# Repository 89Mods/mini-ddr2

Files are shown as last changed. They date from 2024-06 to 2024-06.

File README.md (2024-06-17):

# mini-ddr2

DDR2 Memory Controller fit into a 1€ MAX II CPLD with just 240 LUs. Its incredibly slow, but works!

Currently only works with x4 DRAMs. To demonstrate basic functionality, the CPLD is programmed to respond to byte-wide reads/writes on a "flat" address/data bus. ``A_f`` are the 24 address lines, ``Q_f`` is the data bus. Operation is controlled via ``WEb_f`` and ``CS_f`` (not to be confused with the similarly-named DDR2 signals). A ``ready`` output indicates if the last read/write request has completed processing.

# Implementation Details

After releasing the reset input, the CPLD runs through the DDR2 initialization sequence. Slowly. I optimized it for size, not speed, so it takes several tens of thousands of clock cycles to complete. Once it does, the controller enters the main state machine.

When idle, the controller spams DDR2 refresh commands as fast as it can, only interrupted by a falling edge on ``CS_f`` requesting a memory access. ``A_f`` is split into a bank, column and row address and the proper bank and column activated before the memory access.

Both reads and writes use the minimum burst length of 4, but are only byte-wide, using the first two nibbles in the burst, least-significant half first.

At the start of any read or write leaving the idle loop, the controller starts a timer, only precharging the current bank and returning to idle mode once this expires. This allows for further reads or writes to the same bank and row to be registered and processed immediatly.

If the bank or row change, a precharge and then activate are executed to switch to the new addresses. This does not reset the timer.

# Timing

Max tested clock speed for the CPLD is 85MHz. This is divided by two to arrive at the DDR2 clock of 42.5MHz. Works fine, despite violating the min clock speed for the DDR2 chip in the example by over 150MHz.

Quartus says the design does not meet timings above this clock speed. Propagation delay times begin to mess with the timing at this stage anyways.

The best-case scenario is a sequential write, taking 12 CPLD clock cycles (141ns).

The worst case is a non-sequential read requiring a switch to a different row, at 22 CPLD clock cycles (258ns).

It may be possible to improve this by playing with the timing parameters. Sadly, this design uses 240/240 LUs, so there is otherwise no more room for improvement.

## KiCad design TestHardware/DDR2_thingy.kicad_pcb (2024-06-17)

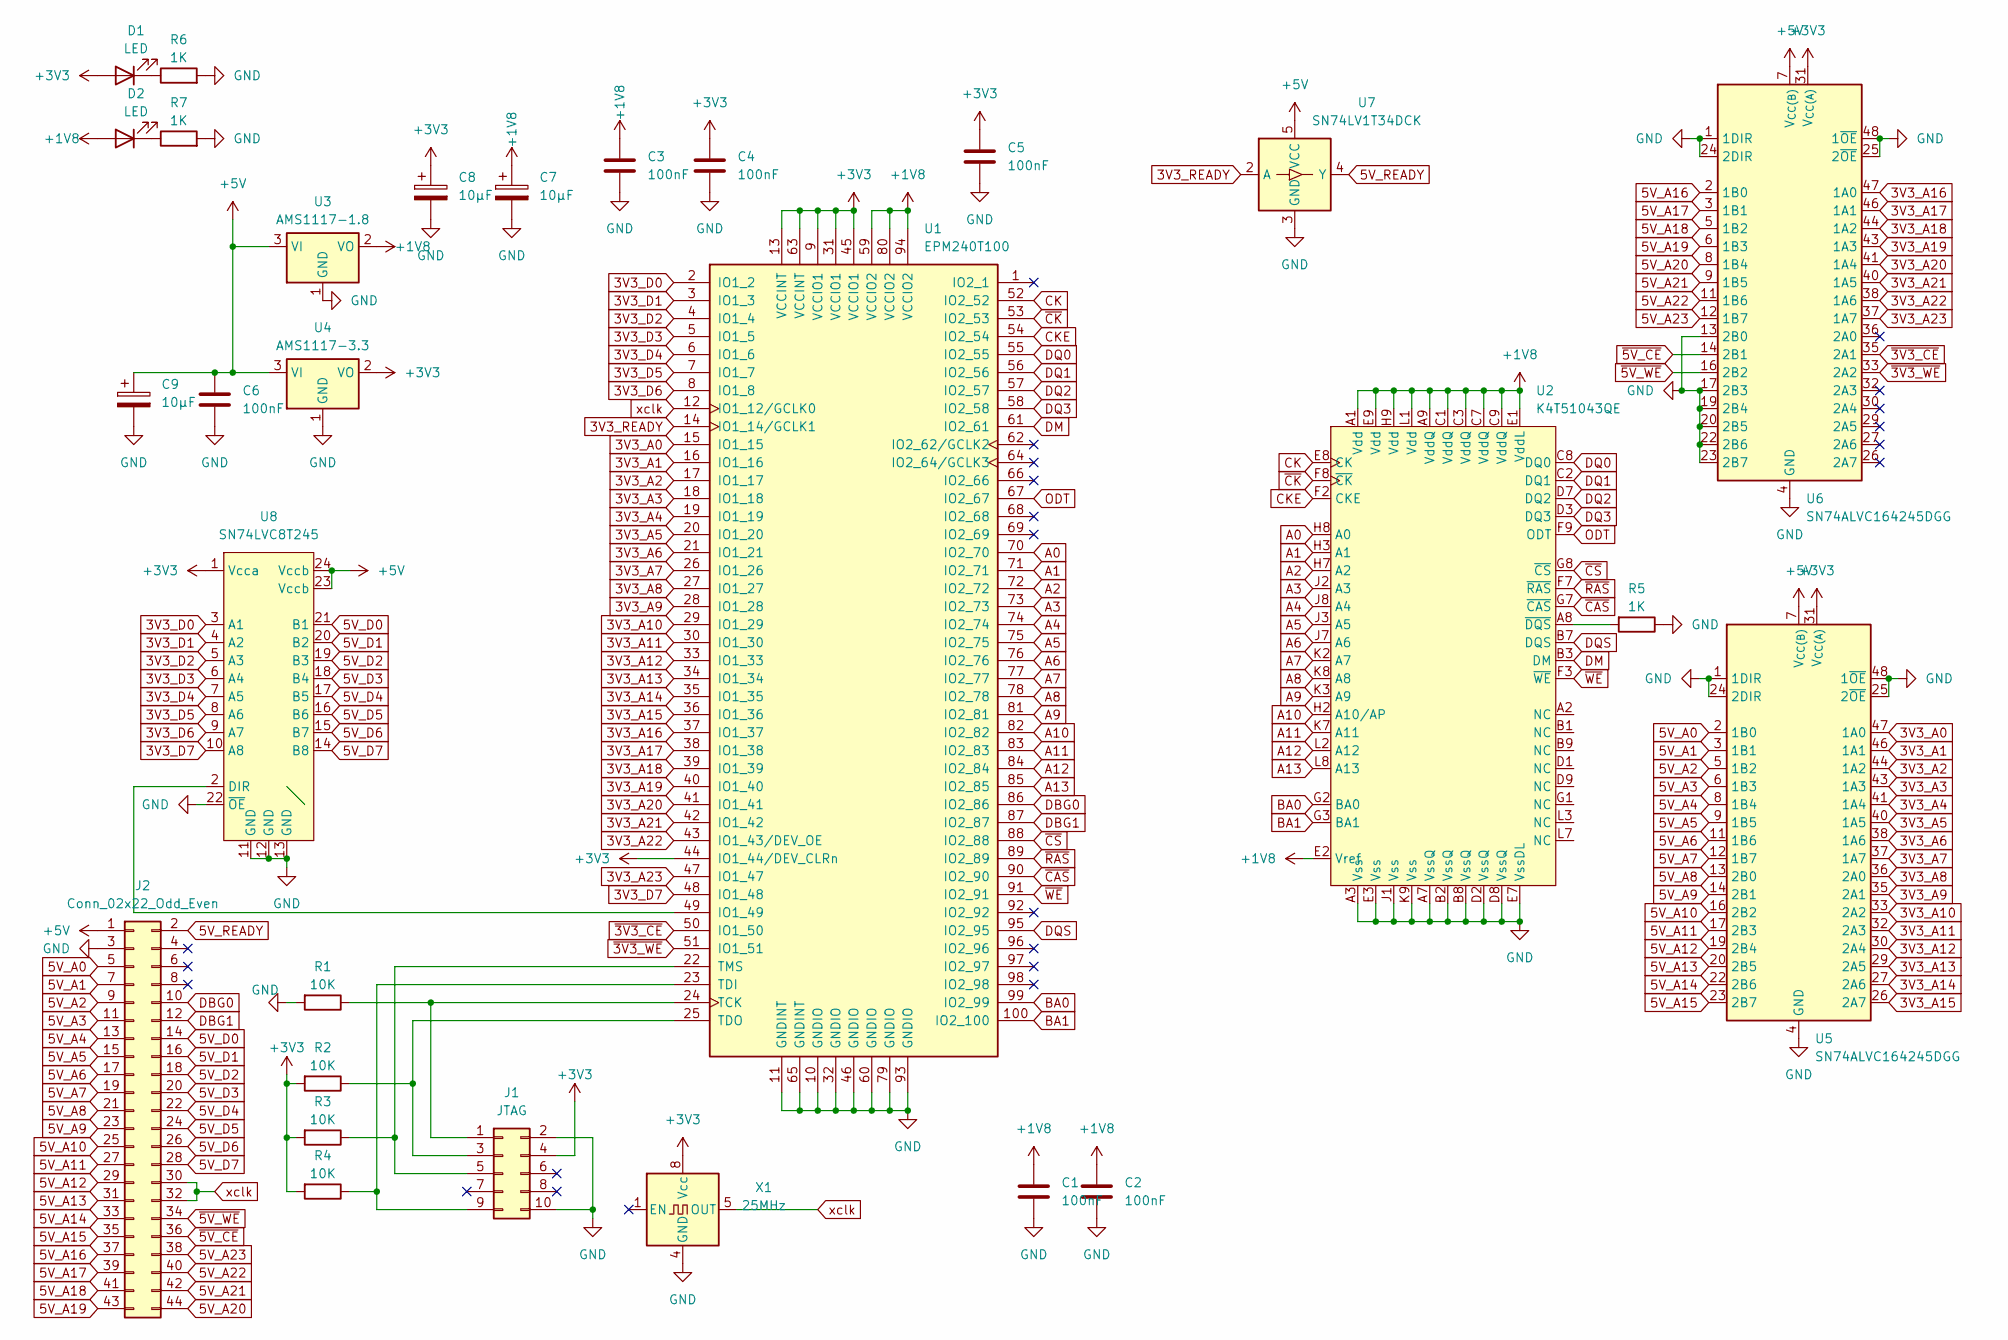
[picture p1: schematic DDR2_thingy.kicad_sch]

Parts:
C1, C2, C3, C4, C5, C6: 100nF; C_0805_2012Metric_Pad1.18x1.45mm_HandSolder
C7, C8, C9: 10µF; CP_Elec_3x5.4
D1, D2: LED; LED_1206_3216Metric_Pad1.42x1.75mm_HandSolder
J1: JTAG; PinHeader_2x05_P2.54mm_Vertical
J2: Conn_02x22_Odd_Even; PinHeader_2x22_P2.54mm_Vertical
R1, R2, R3, R4: 10K; R_1206_3216Metric_Pad1.30x1.75mm_HandSolder
R5: 1K; R_1206_3216Metric_Pad1.30x1.75mm_HandSolder
R6, R7: 1K; R_2010_5025Metric_Pad1.40x2.65mm_HandSolder
U1: EPM240T100; LQFP-100_14x14mm_P0.5mm
U2: K4T51043QE; BGA_for_those_ddr2_ics_1
U3: AMS1117-1.8; SOT-223-3_TabPin2
U4: AMS1117-3.3; SOT-223-3_TabPin2
U5, U6: SN74ALVC164245DGG; TSSOP-48_6.1x12.5mm_P0.5mm
U7: SN74LV1T34DCK; SOT-23-5
U8: SN74LVC8T245; TSSOP-24_4.4x7.8mm_P0.65mm
X1: 25MHz; Oscillator_DIP-8

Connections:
3V3_A0: U1.15 (IO1_15), U5.47 (1A0)
3V3_A1: U1.16 (IO1_16), U5.46 (1A1)
3V3_A2: U1.17 (IO1_17), U5.44 (1A2)
3V3_A3: U1.18 (IO1_18), U5.43 (1A3)
3V3_A4: U1.19 (IO1_19), U5.41 (1A4)
3V3_A5: U1.20 (IO1_20), U5.40 (1A5)
3V3_A6: U1.21 (IO1_21), U5.38 (1A6)
3V3_A7: U1.26 (IO1_26), U5.37 (1A7)
3V3_A8: U1.27 (IO1_27), U5.36 (2A0)
3V3_A9: U1.28 (IO1_28), U5.35 (2A1)
3V3_A10: U1.29 (IO1_29), U5.33 (2A2)
3V3_A11: U1.30 (IO1_30), U5.32 (2A3)
3V3_A12: U1.33 (IO1_33), U5.30 (2A4)
3V3_A13: U1.34 (IO1_34), U5.29 (2A5)
3V3_A14: U1.35 (IO1_35), U5.27 (2A6)
3V3_A15: U1.36 (IO1_36), U5.26 (2A7)
3V3_A16: U1.37 (IO1_37), U6.47 (1A0)
3V3_A17: U1.38 (IO1_38), U6.46 (1A1)
3V3_A18: U1.39 (IO1_39), U6.44 (1A2)
3V3_A19: U1.40 (IO1_40), U6.43 (1A3)
3V3_A20: U1.41 (IO1_41), U6.41 (1A4)
3V3_A21: U1.42 (IO1_42), U6.40 (1A5)
3V3_A22: U1.43 (IO1_43/DEV_OE), U6.38 (1A6)
3V3_A23: U1.47 (IO1_47), U6.37 (1A7)
3V3_D0: U1.2 (IO1_2), U8.3 (A1)
3V3_D1: U1.3 (IO1_3), U8.4 (A2)
3V3_D2: U1.4 (IO1_4), U8.5 (A3)
3V3_D3: U1.5 (IO1_5), U8.6 (A4)
3V3_D4: U1.6 (IO1_6), U8.7 (A5)
3V3_D5: U1.7 (IO1_7), U8.8 (A6)
3V3_D6: U1.8 (IO1_8), U8.9 (A7)
3V3_D7: U1.48 (IO1_48), U8.10 (A8)
3V3_READY: U1.14 (IO1_14/GCLK1), U7.2 (A)
5V_A0: J2.5, U5.2 (1B0)
5V_A1: J2.7, U5.3 (1B1)
5V_A2: J2.9, U5.5 (1B2)
5V_A3: J2.11, U5.6 (1B3)
5V_A4: J2.13, U5.8 (1B4)
5V_A5: J2.15, U5.9 (1B5)
5V_A6: J2.17, U5.11 (1B6)
5V_A7: J2.19, U5.12 (1B7)
5V_A8: J2.21, U5.13 (2B0)
5V_A9: J2.23, U5.14 (2B1)
5V_A10: J2.25, U5.16 (2B2)
5V_A11: J2.27, U5.17 (2B3)
5V_A12: J2.29, U5.19 (2B4)
5V_A13: J2.31, U5.20 (2B5)
5V_A14: J2.33, U5.22 (2B6)
5V_A15: J2.35, U5.23 (2B7)
5V_A16: J2.37, U6.2 (1B0)
5V_A17: J2.39, U6.3 (1B1)
5V_A18: J2.41, U6.5 (1B2)
5V_A19: J2.43, U6.6 (1B3)
5V_A20: J2.44, U6.8 (1B4)
5V_A21: J2.42, U6.9 (1B5)
5V_A22: J2.40, U6.11 (1B6)
5V_A23: J2.38, U6.12 (1B7)
5V_D0: J2.14, U8.21 (B1)
5V_D1: J2.16, U8.20 (B2)
5V_D2: J2.18, U8.19 (B3)
5V_D3: J2.20, U8.18 (B4)
5V_D4: J2.22, U8.17 (B5)
5V_D5: J2.24, U8.16 (B6)
5V_D6: J2.26, U8.15 (B7)
5V_D7: J2.28, U8.14 (B8)
5V_READY: J2.2, U7.4 (Y)
+1V8: C1.1, C2.1, C3.1, C7.1, D2.2 (A), U1.59 (VCCIO2), U1.80 (VCCIO2), U1.94 (VCCIO2), U2.A1 (Vdd), U2.A9 (VddQ), U2.C1 (VddQ), U2.C3 (VddQ), U2.C7 (VddQ), U2.C9 (VddQ), U2.E1 (VddL), U2.E2 (Vref), U2.E9 (Vdd), U2.H9 (Vdd), U2.L1 (Vdd), U3.2 (VO)
+3V3: C4.1, C5.1, C8.1, D1.2 (A), J1.4, R2.2, R3.2, R4.2, U1.9 (VCCIO1), U1.13 (VCCINT), U1.31 (VCCIO1), U1.44 (IO1_44/DEV_CLRn), U1.45 (VCCIO1), U1.63 (VCCINT), U4.2 (VO), U5.31 (V_{CC(A)}), U5.42 (V_{CC(A)}), U6.31 (V_{CC(A)}), U6.42 (V_{CC(A)}), U8.1 (Vcca), X1.8 (Vcc)
+5V: C6.1, C9.1, J2.1, U3.3 (VI), U4.3 (VI), U5.7 (V_{CC(B)}), U5.18 (V_{CC(B)}), U6.7 (V_{CC(B)}), U6.18 (V_{CC(B)}), U7.5 (VCC), U8.23 (Vccb), U8.24 (Vccb)
A0: U1.70 (IO2_70), U2.H8 (A0)
A1: U1.71 (IO2_71), U2.H3 (A1)
A2: U1.72 (IO2_72), U2.H7 (A2)
A3: U1.73 (IO2_73), U2.J2 (A3)
A4: U1.74 (IO2_74), U2.J8 (A4)
A5: U1.75 (IO2_75), U2.J3 (A5)
A6: U1.76 (IO2_76), U2.J7 (A6)
A7: U1.77 (IO2_77), U2.K2 (A7)
A8: U1.78 (IO2_78), U2.K8 (A8)
A9: U1.81 (IO2_81), U2.K3 (A9)
A10: U1.82 (IO2_82), U2.H2 (A10/AP)
A11: U1.83 (IO2_83), U2.K7 (A11)
A12: U1.84 (IO2_84), U2.L2 (A12)
A13: U1.85 (IO2_85), U2.L8 (A13)
BA0: U1.99 (IO2_99), U2.G2 (BA0)
BA1: U1.100 (IO2_100), U2.G3 (BA1)
CK: U1.52 (IO2_52), U2.E8 (CK)
CKE: U1.54 (IO2_54), U2.F2 (CKE)
DBG0: J2.10, U1.86 (IO2_86)
DBG1: J2.12, U1.87 (IO2_87)
DM: U1.61 (IO2_61), U2.B3 (DM)
DQ0: U1.55 (IO2_55), U2.C8 (DQ0)
DQ1: U1.56 (IO2_56), U2.C2 (DQ1)
DQ2: U1.57 (IO2_57), U2.D7 (DQ2)
DQ3: U1.58 (IO2_58), U2.D3 (DQ3)
DQS: U1.95 (IO2_95), U2.B7 (DQS)
GND: C1.2, C2.2, C3.2, C4.2, C5.2, C6.2, C7.2, C8.2, C9.2, J1.2, J1.10, J2.3, R1.2, R5.1, R6.2, R7.2, U1.10 (GNDIO), U1.11 (GNDINT), U1.32 (GNDIO), U1.46 (GNDIO), U1.60 (GNDIO), U1.65 (GNDINT), U1.79 (GNDIO), U1.93 (GNDIO), U2.A3 (Vss), U2.A7 (VssQ), U2.B2 (VssQ), U2.B8 (VssQ), U2.D2 (VssQ), U2.D8 (VssQ), U2.E3 (Vss), U2.E7 (VssDL), U2.J1 (Vss), U2.K9 (Vss), U3.1 (GND), U4.1 (GND), U5.1 (1DIR), U5.4 (GND), U5.10 (GND), U5.15 (GND), U5.21 (GND), U5.24 (2DIR), U5.25 (2~OE), U5.28 (GND), U5.34 (GND), U5.39 (GND), U5.45 (GND), U5.48 (1~OE), U6.1 (1DIR), U6.4 (GND), U6.10 (GND), U6.13 (2B0), U6.15 (GND), U6.17 (2B3), U6.19 (2B4), U6.20 (2B5), U6.21 (GND), U6.22 (2B6), U6.23 (2B7), U6.24 (2DIR), U6.25 (2~OE), U6.28 (GND), U6.34 (GND), U6.39 (GND), U6.45 (GND), U6.48 (1~OE), U7.3 (GND), U8.11 (GND), U8.12 (GND), U8.13 (GND), U8.22 (~OE), X1.4 (GND)
unnamed: D1.1 (K), R6.1
unnamed: D2.1 (K), R7.1
unnamed: J1.1, R1.1, U1.24 (TCK)
unnamed: J1.3, R2.1, U1.25 (TDO)
unnamed: J1.5, R3.1, U1.22 (TMS)
unnamed: J1.9, R4.1, U1.23 (TDI)
unnamed: U1.49 (IO1_49), U8.2 (DIR)
unnamed: R5.2, U2.A8 (~DQS)
ODT: U1.67 (IO2_67), U2.F9 (ODT)
xclk: J2.30, J2.32, U1.12 (IO1_12/GCLK0), X1.5 (OUT)
~3V3_CE: U1.50 (IO1_50), U6.35 (2A1)
~3V3_WE: U1.51 (IO1_51), U6.33 (2A2)
~5V_CE: J2.36, U6.14 (2B1)
~5V_WE: J2.34, U6.16 (2B2)
~CAS: U1.90 (IO2_90), U2.G7 (~CAS)
~CK: U1.53 (IO2_53), U2.F8 (~CK)
~CS: U1.88 (IO2_88), U2.G8 (~CS)
~RAS: U1.89 (IO2_89), U2.F7 (~RAS)
~WE: U1.91 (IO2_91), U2.F3 (~WE)

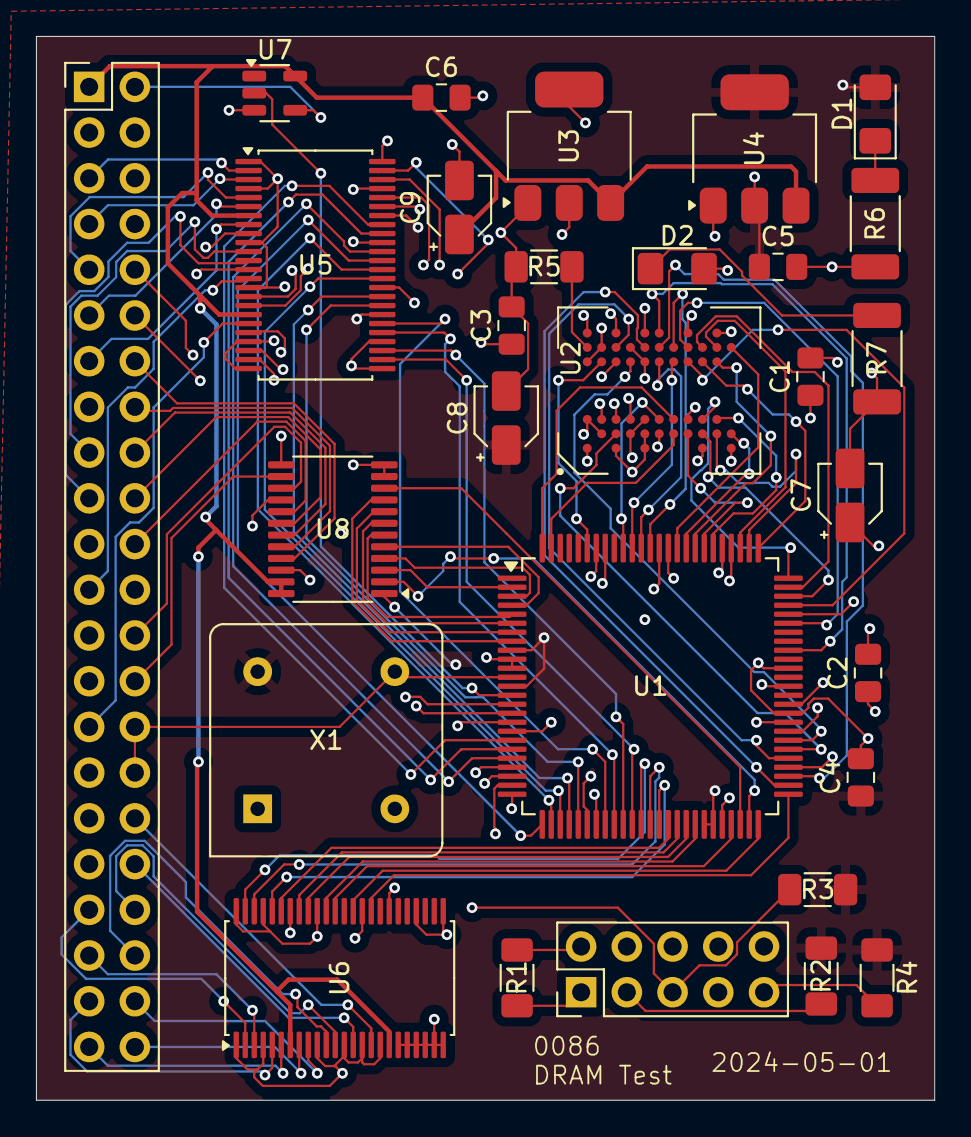
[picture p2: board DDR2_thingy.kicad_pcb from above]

Board: 4 copper layers, 49.9 x 59.1 mm, 29 parts (0 on the bottom side), 115 nets.

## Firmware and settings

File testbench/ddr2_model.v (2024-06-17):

/****************************************************************************************
*
*    File Name:  ddr2_model.v
*      Version:  5.82
*        Model:  BUS Functional
*
* Dependencies:  ddr2_model_parameters.vh
*
*  Description:  Micron SDRAM DDR2 (Double Data Rate 2)
*
*   Limitation:  - doesn't check for average refresh timings
*                - positive ck and ck_n edges are used to form internal clock
*                - positive dqs and dqs_n edges are used to latch data
*                - test mode is not modeled
*
*         Note:  - Set simulator resolution to "ps" accuracy
*                - Set Debug = 0 to disable $display messages
*
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
*                Copyright 2003 Micron Technology, Inc. All rights reserved.
*
* Rev   Author   Date        Changes
* ---------------------------------------------------------------------------------------
* 1.00  JMK      07/29/03    Initial Release
* 1.10  JMK      08/09/03    Timing Parameter updates to tIS, tIH, tDS, tDH
* 2.20  JMK      08/07/03    General cleanup
* 2.30  JMK      11/26/03    Added CL_MIN, CL_MAX, wl_min and wl_max parameters.
*                            Added AL_MIN and AL_MAX parameters.
*                            Removed support for OCD.
* 2.40  JMK      01/15/04    Removed verilog 2001 constructs.
* 2.50  JMK      01/29/04    Removed tRP checks during Precharge command.
* 2.60  JMK      04/20/04    Fixed tWTR check.
* 2.70  JMK      04/30/04    Added tRFC maximum check.
*                            Combined Self Refresh and Power Down always blocks.
*                            Added Reset Function (CKE LOW Anytime).
* 2.80  JMK      08/19/04    Precharge is treated as NOP when bank is not active.  
*                            Added checks for tRAS, tWR, tRTP to any bank during Pre-All.
*                            tRFC maximum violation will only display one time.
* 2.90  JMK      11/05/04    Fixed DQS checking during write.
*                            Fixed false tRFC max assertion during power up and self ref.
*                            Added warning for 200us CKE low time during initialization.
*                            Added -3, -3E, and -37V speed grades to ddr2_parameters.v
* 3.00  JMK      04/22/05    Removed ODT off requirement during power down.
*                            Added tAOND, tAOFD, tANPD, tAXPD, tAONPD, and tAOFPD parameters.
*                            Added ODT status messages.
*                            Updated the initialization sequence.
*                            Disable ODT and CLK pins during self refresh.
*                            Disable cmd and addr pins during power down and self refresh.
* 3.10  JMK      06/07/05    Disable trpa checking if the part does not have 8 banks.
*                            Changed tAXPD message from error to a warning.
*                            Added tDSS checking.
*                            Removed tDQSL checking during tWPRE and tWPST.
*                            Fixed a burst order error during writes.
*                            Renamed parameters file with .vh extension.
* 3.20  JMK      07/18/05    Removed 14 tCK requirement from LMR to READ.
* 3.30  JMK      08/03/05    Added check for interrupting a burst with auto precharge.
* 4.00  JMK      11/21/05    Parameter names all UPPERCASE, signal names all lowercase.
*                            Clock jitter can be tolerated within specification range.
*                            Clock frequency is sampled from the CK pin.
*                            Scaleable up to 64 DQ and 16 DQS bits.
*                            Read data can be randomly skewed using RANDOM_OUT_DELAY.
*                            Parameterized read and write DQS, and read DQ.
*                            Initialization can be bypassed using initialize task.
* 4.10  JMK      11/30/05    Fixed compile errors when `MAX_MEM was defined.
* 4.20  JMK      12/09/05    Fixed memory addressing error when `MAX_MEM was defined.
* 4.30  JMK      02/15/06    Added dummy write to initialization sequence.
*                            Removed tWPST maximum checking.
*                            Rising dqs_n edge latches data when enabled in EMR.
*                            Fixed a sign error in the tJIT(cc) calculation.
* 4.40  JMK      02/16/06    Fixed dummy write when`MAX_MEM was defined.
* 4.50  JMK      02/27/06    Fixed extra tDQSS assertions.
*                            Fixed tRCD and tWTR checking.
*                            Errors entering Power Down or Self Refresh will cause reset.
*                            Ignore dqs_n when disabled in EMR.
* 5.00  JMK      04/24/06    Test stimulus now included from external file (subtest.vh)
*                            Fixed tRFC max assertion during self refresh.
*                            Fixed tANPD checking during Power Down.
*                            Removed dummy write from initialization sequence.
* 5.01  JMK      04/28/06    Fixed Auto Precharge to Load Mode, Refresh and Self Refresh.
*                            Removed Auto Precharge error message during Power Down Enter.
* 5.10  JMK      07/26/06    Created internal clock using ck and ck_n.
*                            RDQS can only be enabled in EMR for x8 configurations.
*                            CAS latency is checked vs frequency when DLL locks.
*                            tMOD changed from tCK units to ns units.
*                            Added 50 Ohm setting for Rtt in EMR.
*                            Improved checking of DQS during writes.
* 5.20  JMK      10/02/06    Fixed DQS checking for interrupting write to write and x16.
* 5.30  JMK      05/25/07    Fixed checking for 0-Z transition on write postamble.
* 5.50  JMK      05/30/08    Renamed ddr2_dimm.v to ddr2_module.v and added SODIMM support.
*                            Added a register delay to ddr2_module.v when RDIMM is defined.
*                            Added multi-chip package model support in ddr2_mcp.v
*                            Added High Temp Self Refresh rate setting in EMRS2[7]
* 5.70  JMK      04/23/09    Updated tRPA definition
*                            Increased internal width to 72 bit DQ bus
* 5.80  SPH      08/12/09    Fixed tRAS maximum violation (only check if bank still open)
* 5.81  SPH      12/08/09    Only check tIH for cmd_addr if CS# LOW
* 5.82  SPH      04/08/10    Correct debug message for SRT in EMR2         
* 5.81  SPH      12/08/09    Only check tIH for cmd_addr if CS# LOW
* 5.81  SPH      12/08/09    Only check tIH for cmd_addr if CS# LOW
****************************************************************************************/

// DO NOT CHANGE THE TIMESCALE
// MAKE SURE YOUR SIMULATOR USES "PS" RESOLUTION
`timescale 1ps / 1ps
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

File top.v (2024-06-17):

//Constants for the particular RAM chip I used
//Timing parameters based on CPLD @ 80MHz
//This has the DDR2 clocked at 40MHz

//Defines for MR settings
`define MR_BURST_LEN_4 'b010
`define MR_BURST_LEN_8 'b011
`define MR_BURST_SEQUENTIAL 0
`define MR_BURST_INTERLEAVED (1 << 3)
`define MR_CAS_LATENCY(x) (x << 4)
`define MR_MODE_TEST (1 << 7)
`define MR_MODE_NORMAL 0
`define MR_DLL_RESET (1 << 8)
`define MR_WRITE_RECOVERY(x) ((x - 1) << 9)
`define MR_PD_FAST 0
`define MR_PD_SLOW (1 << 12)

`define CAS_LATENCY 3 //What goes into the MR
//Actual delays the controller takes
`define WRITE_LATENCY (`CAS_LATENCY-1)
`define READ_LATENCY (`CAS_LATENCY)

`define READ_RECOVERY 0 //How long the controller will delay after a read
`define WRITE_RECOVERY_SETTING 2 //This is what goes in the MR
`define WRITE_RECOVERY 2 //This is how much delay the controller will actually take after a write

`define MR_SETTING (`MR_BURST_LEN_4 | `MR_BURST_SEQUENTIAL | `MR_CAS_LATENCY(`CAS_LATENCY) | `MR_MODE_NORMAL | `MR_WRITE_RECOVERY(`WRITE_RECOVERY_SETTING) | `MR_PD_FAST)

//Defines for EMR settings
`define EMR_DLL_NORMAL 0
`define EMR_DLL_TEST 1
`define EMR_FULL_STRENGTH 0
`define EMR_REDUCED_STRENGTH (1 << 1)
`define EMR_R_DISABLED 0
`define EMR_R_75 (1 << 2)
`define EMR_R_150 (1 << 6)
`define EMR_R_50 ((1 << 2) | (1 << 6))
`define EMR_AL(x) (x << 3)
`define EMR_OCD_EXIT 0
`define EMR_OCD_DEFAULTS (7 << 7)
`define EMR_NDQS_ON 0
`define EMR_NDQS_OFF (1 << 10)
`define EMR_RDQS_OFF 0
`define EMR_RDQS_ON (1 << 11)
`define EMR_OUTS_ON 0
`define EMR_OUTS_OFF (1 << 12)

`define EMR_SETTING (`EMR_DLL_NORMAL | `EMR_R_150 | `EMR_FULL_STRENGTH | `EMR_AL(0) | `EMR_NDQS_OFF | `EMR_RDQS_OFF)

//How many clock cycles correspond to one tRFC
`define REFRESH_WAIT 4

//How many clock cycles correspond to one tRP
`define PRECHARGE_WAIT 1

//How many clock cycles correspond to one tRCD (activate command)
//Minimum value of 1
//(I found real hardware glitches out when this is 0)
`define TRCD_CYCLES 1

`undef WITH_HEARTBEAT
`define EARLY_READY

//Change if you need DQS_b. Also requires it be enabled in the EMR setting above
`undef WITH_DQSB

module dram_controller(
	input clk,
	output reg ddr_clk = 0,
	output ddr_clk_c,
	inout [3:0] Q,
	output reg CS_b = 1,
	output reg ODT = 0,
	output reg RAS_b = 1,
	output reg CAS_b,
	output reg WE_b = 1,
	output reg [1:0] BA = 0,
	output [13:0] A,
	inout DQS,
	output DM,
	output reg CKE = 0,

	/*
	 * Flat memory interface
	 */
	input CEb_in,
	inout [7:0] Q_f,
	input WEb_f,
	input [22:0] A_f,
	input rst_b,
	inout DQS_b,
	output ready,
	output bdir, //Bus direction for level shifter
	output dbg
);
wire [25:0] full_addr = {3'b00, A_f[22:0]};

wire reset = !rst_b;

assign Q = writing ? (rw_step >= 2 ? Q_f[3:0] : Q_f[7:4]) : 4'hz;
assign DQS = writing ? DQS_ll : 1'bz;
`ifdef WITH_DQSB
assign DQS_b = writing ? !DQS_ll : 1'bz; //optional DQS_b
`else
assign DQS_b = !init_done;
`endif
assign DM = !writing || rw_step == 0 || !counter_expired;

/*
 * Define address bus value
 * During init sequence, taken from below table
 * During normal operation, row address during ACTIVATE, column address otherwise
 * Note that A10 in the column address is always low
 */
reg [13:0] init_A;
always @(*) begin
	casez(init_step)
		default: init_A = 0;
		7'b?000101: init_A = 1<<10;
		7'b?010001: init_A = `MR_DLL_RESET;
		7'b?010100: init_A = 1<<10;
		7'b?011110: init_A = `MR_SETTING;
		7'b?100001: init_A = `EMR_SETTING | `EMR_OCD_DEFAULTS;
		7'b?100100: init_A = `EMR_SETTING;
	endcase
end

/*
 * Bank address during init sequence, combines with above table
 */
reg [1:0] BA_init;
always @(*) begin
	casez(init_step)
		default: BA_init = 2'bxx; //Don’t care
		7'b?000111: BA_init = 2'b10;
		7'b?001010: BA_init = 2'b11;
		7'b?001101: BA_init = 2'b01;
		7'b?010000: BA_init = 2'b00;
		7'b?011101: BA_init = 2'b00;
		7'b?100000: BA_init = 2'b01;
		7'b?100011: BA_init = 2'b01;
	endcase
end

wire [13:0] ready_A = state == 1 ? row_address : {3'b000, column_address[10], 1'b0, column_address[9:0]};
assign A = init_done ? ready_A : init_A;

assign ddr_clk_c = !ddr_clk;
reg init_done;
reg [2:0] state;
reg [7:0] counter = 255;
reg [1:0] rw_step;
reg [8:0] command_timeout = 0;
reg writing;
reg DQS_l;
reg DQS_ll;
reg last_DQS;
reg ready_l;
reg needs_precharge;
reg [13:0] row_address_l;
reg latch_command = 0;
reg [6:0] init_step;
reg CE_edge = 1;
reg CE_edge_edge = 1;
reg [7:0] dbuff;

wire [7:0] counter_dec = counter - 1;
wire counter_expired = counter == 0;

assign bdir = WEb_f && !CEb_in;
assign Q_f = bdir ? dbuff : 8'hzz;
assign ready = ready_l && !latch_command;

wire [10:0] column_address = {full_addr[9:0], 1'b0};
wire [13:0] row_address = full_addr[23:10];

`ifdef WITH_HEARTBEAT
//Just an LED blinker
reg [23:0] test = 0;
assign dbg = test[23];
`else
assign dbg = dbuff[7];
`endif

always @(negedge clk) DQS_ll <= DQS_l;
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
